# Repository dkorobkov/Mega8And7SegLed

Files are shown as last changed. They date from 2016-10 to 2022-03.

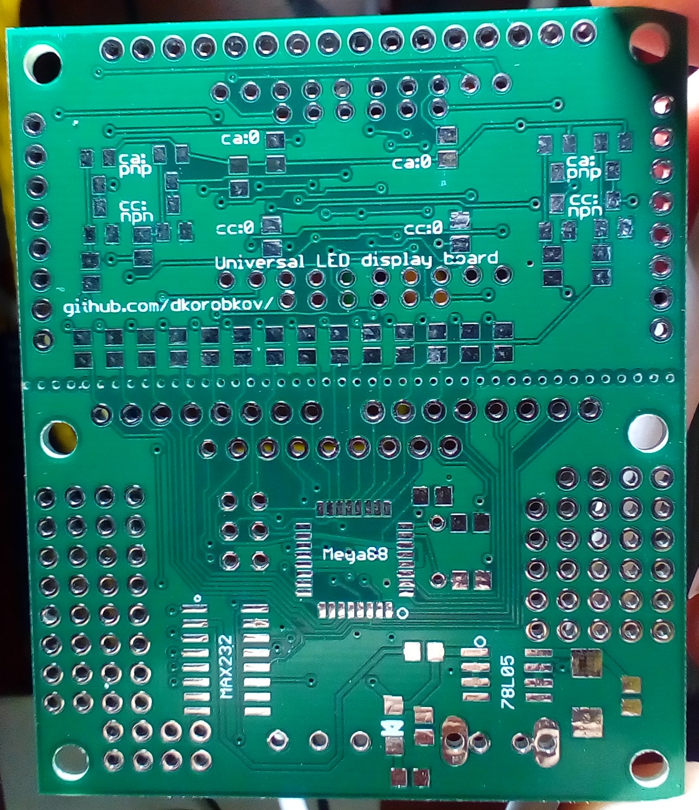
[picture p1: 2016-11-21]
board_bottom.JPG

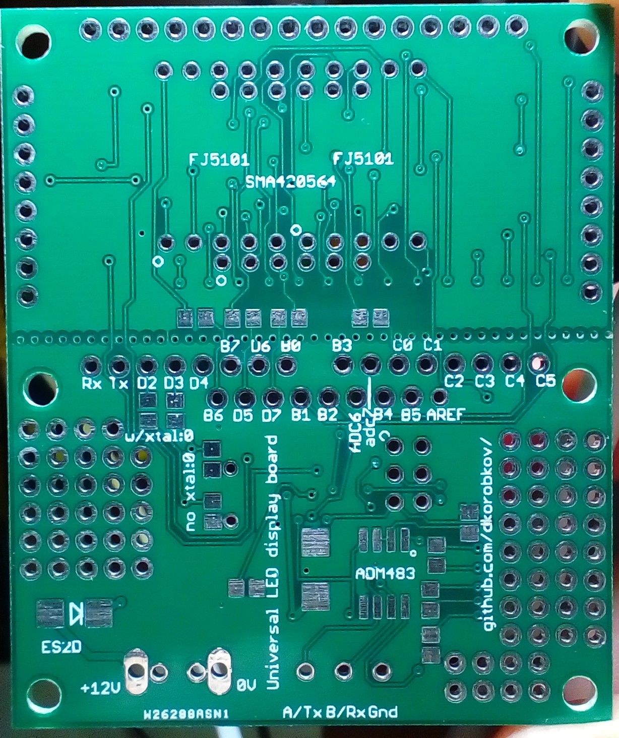
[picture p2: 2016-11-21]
board_top.JPG

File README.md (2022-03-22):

# Mega8And7SegLed
Universal PCB (55*65 mm) with Atmega8 (TQFP32), VUSB and 2-4 digit 7-segment LED (or chinese "Nokia 5110" LCD) for generic projects. EAGLE files and Gerber, Atmel Studio 6.2 example project (C).

See https://github.com/dkorobkov/Mega8And7SegLed/blob/master/board_top.JPG for board look and 
https://github.com/dkorobkov/Mega8And7SegLed/blob/master/LEDBoard.mp4 for its operation.

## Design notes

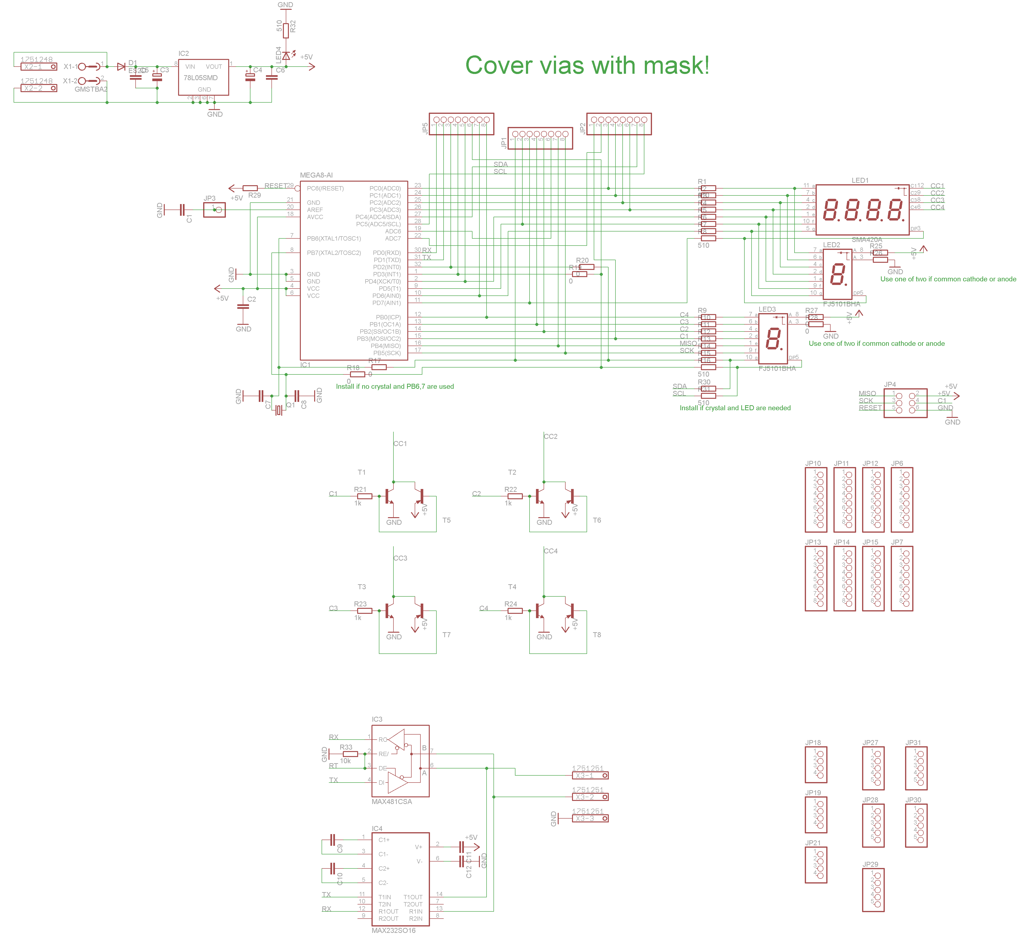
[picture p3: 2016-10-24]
schematic.png

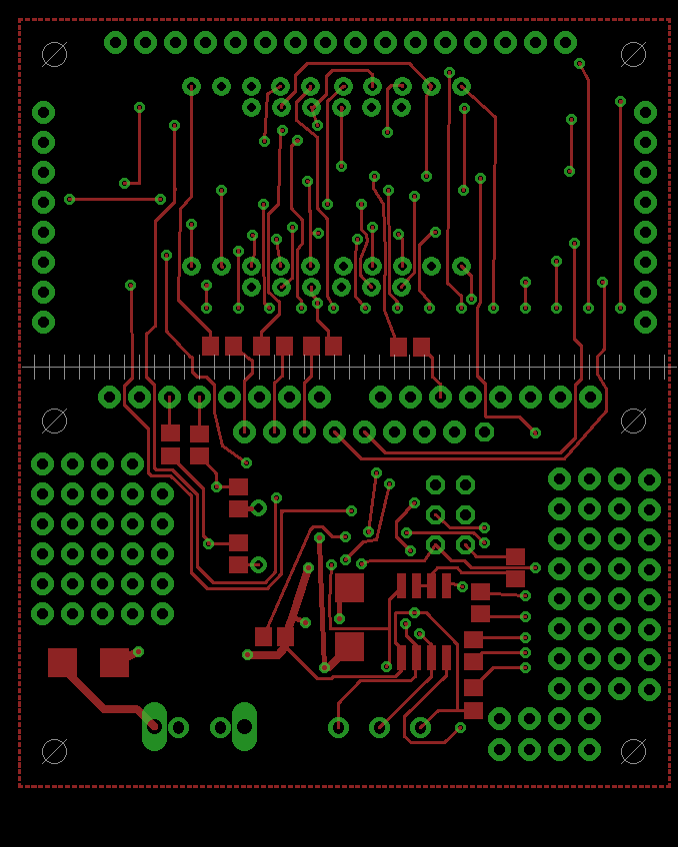
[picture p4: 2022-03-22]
top.png

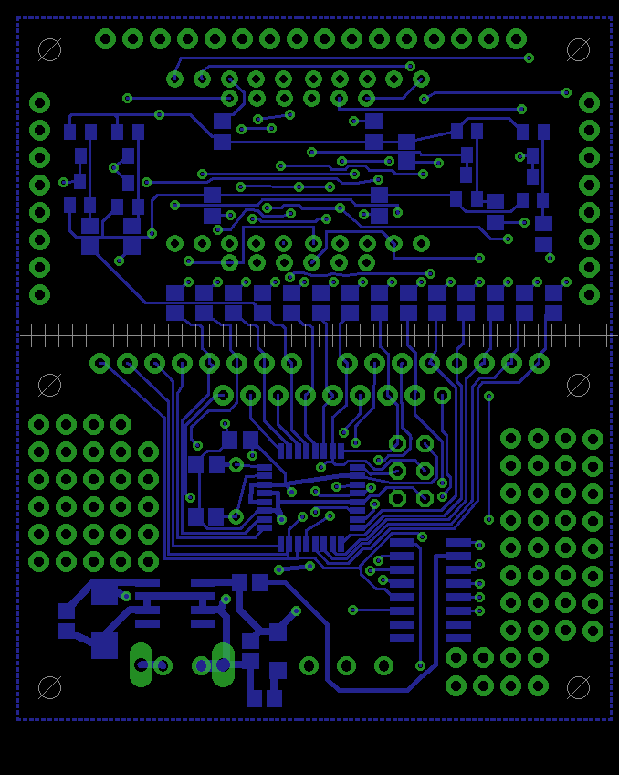
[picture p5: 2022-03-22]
bottom.png

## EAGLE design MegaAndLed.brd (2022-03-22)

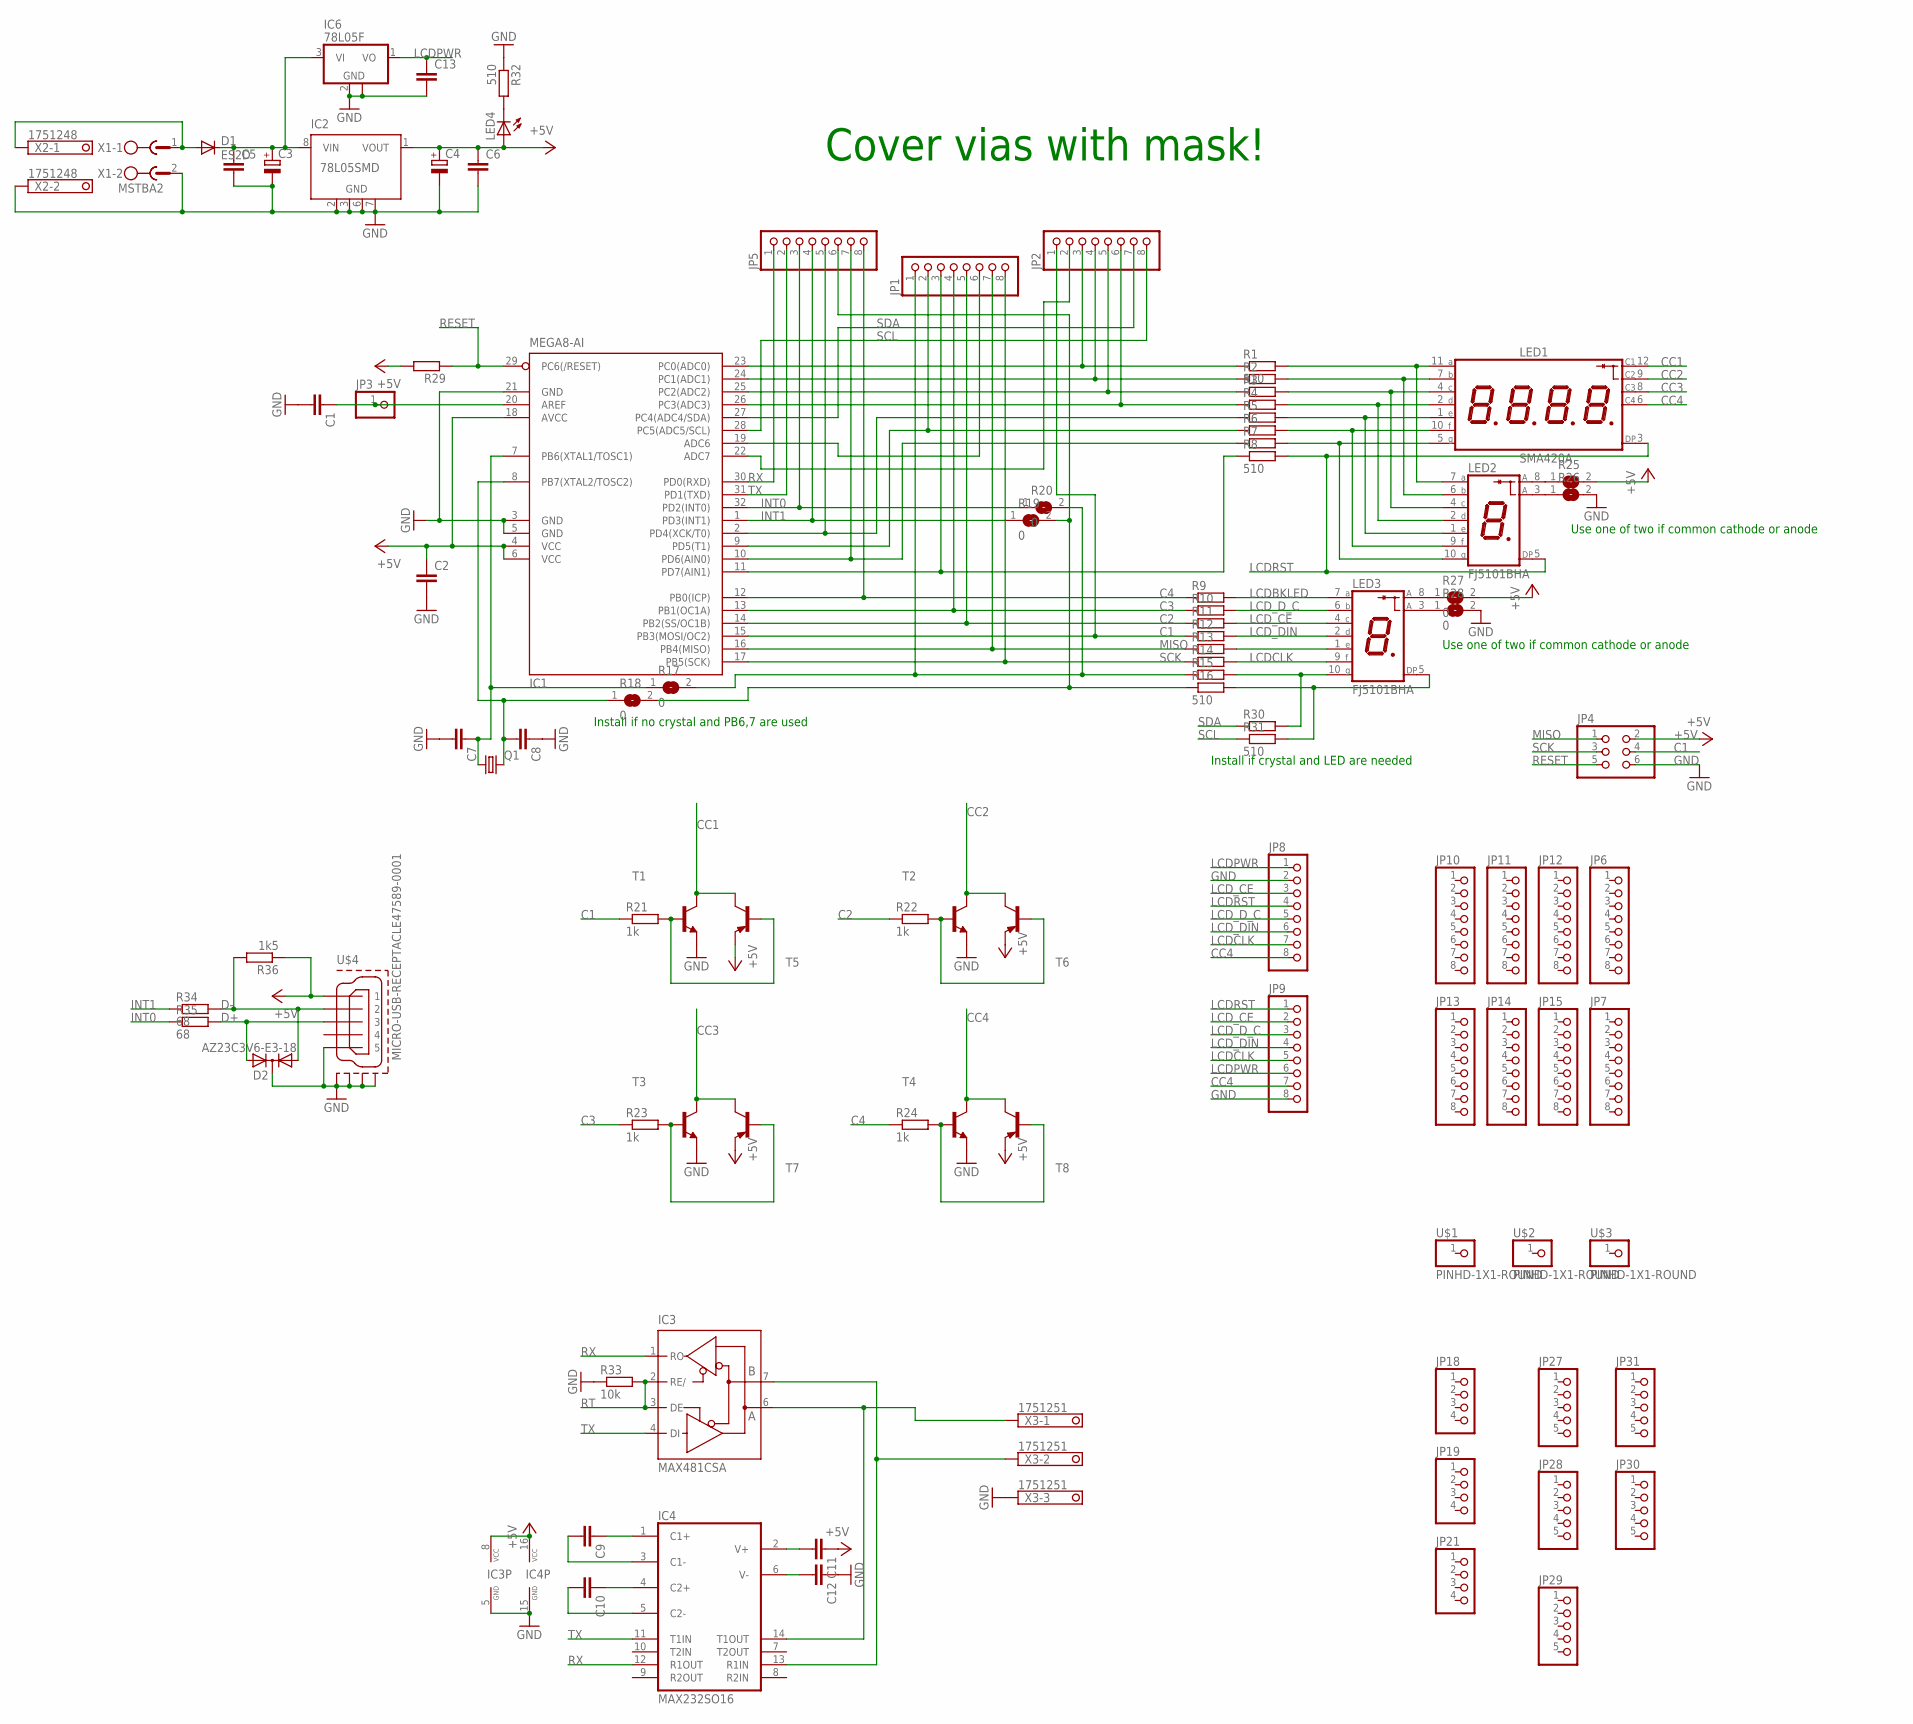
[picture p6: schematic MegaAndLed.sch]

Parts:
C1, C2, C5, C6, C7, C8, C9, C10, C11, C12, C13: C-EUC0805; C0805
C3, C4: CPOL-EUSMCC; SMC_C
D1: ES2D; SMB
D2: AZ23C3V6-E3-18; SOT23
IC1: MEGA8-AI; TQFP32-08
IC2: 78L05SMD; SO08
IC3: MAX481CSA; SO08
IC4: MAX232SO16; SO16
IC6: 78L05F; SOT89
JP1, JP2, JP5, JP6, JP7, JP8, JP9, JP10, JP11, JP12, JP13, JP14, JP15: PINHD-1X8-ROUND; 1X08-ROUND
JP3: PINHD-1X1; 1X01
JP4: PINHD-2X3; 2X03
JP18, JP19, JP21: PINHD-1X4-ROUND; 1X04-ROUND
JP27, JP28, JP29, JP30, JP31: PINHD-1X5-ROUND; 1X05-ROUND
LED1: SMA420A; 7X4-LED
LED2, LED3: FJ5101BHA; LA-401
LED4: LEDCHIPLED_1206; CHIPLED_1206
Q1: CRYSTALHC49U-H; HC49U-H
R1, R8, R16, R31, R32: 510; R0805
R2, R3, R4, R5, R6, R7, R9, R10, R11, R12, R13, R14, R15, R29, R30: R-EU_R0805; R0805
R17, R18, R19, R20, R27, R28: 0; SJ
R21, R22, R23, R24: 1k; R0805
R25, R26: SJ
R33: 10k; R0805
R34, R35: 68; R0805
R36: 1k5; R0805
T1, T2, T3, T4: BCW31-NPN-SOT23-BEC; SOT23-BEC
T5, T6, T7, T8: MMBTA56-SOT23; SOT23
U$1, U$2, U$3: PINHD-1X1-ROUND; 1X01-ROUND
U$4: MICRO-USB-RECEPTACLE47589-0001; 47589-0001
X1: MSTBA2
X2: 1751248
X3: 1751251

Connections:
+5V: C2.1, C4.+, C6.1, C11.1, IC1.4 (VCC), IC1.6 (VCC), IC1.18 (AVCC), IC2.1 (VOUT), IC3.8 (VCC), IC4.16 (VCC), JP4.2, LED4.A, R25.2, R27.2, R29.2, R36.1, T5.2 (E), T6.2 (E), T7.2 (E), T8.2 (E), U$4.1
C1: IC1.15 (PB3(MOSI/OC2)), JP2.1, JP4.4, R12.1, R21.1
C2: IC1.14 (PB2(SS/OC1B)), JP1.5, R11.1, R22.1
C3: IC1.13 (PB1(OC1A)), JP1.4, R10.1, R23.1
C4: IC1.12 (PB0(ICP)), JP5.8, R9.1, R24.1
CC1: LED1.12 (C), T1.C, T5.3 (C)
CC2: LED1.9 (C), T2.C, T6.3 (C)
CC3: LED1.8 (C), T3.C, T7.3 (C)
CC4: JP8.8, JP9.7, LED1.6 (C), T4.C, T8.3 (C)
D+: D2.2 (A2), R35.2, U$4.3
D-: D2.1 (A1), R34.2, R36.2, U$4.2
GND: C1.2, C2.2, C3.-, C4.-, C5.2, C6.2, C7.2, C8.1, C12.1, C13.2, D2.3 (C), IC1.3 (GND), IC1.5 (GND), IC1.21 (GND), IC2.2 (GND), IC2.3 (GND), IC2.6 (GND), IC2.7 (GND), IC3.5 (GND), IC4.15 (GND), IC6.2 (GND), IC6.2@1 (GND), JP4.6, JP8.2, JP9.8, R26.2, R28.2, R32.1, R33.1, T1.E, T2.E, T3.E, T4.E, U$4.5, U$4.CASING1 (GND1), U$4.CASING2 (GND2), U$4.CASING3 (GND3), U$4.CASING4 (GND4), X1.2, X2.2, X3.3
INT0: IC1.32 (PD2(INT0)), JP5.3, R20.1, R35.1
INT1: IC1.1 (PD3(INT1)), JP5.4, R19.1, R34.1
LCDBKLED: LED3.7 (A), R9.2
LCDCLK: JP8.7, JP9.5, LED3.9 (F), R14.2
LCDPWR: C13.1, IC6.1 (VO), JP8.1, JP9.6
LCDRST: JP8.4, JP9.1, LED1.3 (DP), LED2.5 (DP), R8.2
LCD_CE: JP8.3, JP9.2, LED3.4 (C), R11.2
LCD_DIN: JP8.6, JP9.4, LED3.2 (D), R12.2
LCD_D_C: JP8.5, JP9.3, LED3.6 (B), R10.2
MISO: IC1.16 (PB4(MISO)), JP1.7, JP4.1, R13.1
unnamed: C3.+, C5.1, D1.C, IC2.8 (VIN), IC6.3 (VI)
unnamed: IC1.23 (PC0(ADC0)), JP2.3, R1.1
unnamed: IC1.24 (PC1(ADC1)), JP2.4, R2.1
unnamed: IC1.25 (PC2(ADC2)), JP2.5, R3.1
unnamed: R21.2, T1.B, T5.1 (B)
unnamed: R22.2, T2.B, T6.1 (B)
unnamed: IC1.26 (PC3(ADC3)), JP2.6, R4.1
unnamed: C1.1, IC1.20 (AREF), JP3.1
unnamed: LED2.8 (C), R25.1
unnamed: LED2.3 (C), R26.1
unnamed: LED3.8 (C), R27.1
unnamed: LED3.3 (C), R28.1
unnamed: IC1.19 (ADC6), JP1.6
unnamed: IC1.2 (PD4(XCK/T0)), JP5.5, R5.1
unnamed: R23.2, T3.B, T7.1 (B)
unnamed: R24.2, T4.B, T8.1 (B)
unnamed: IC1.22 (ADC7), JP2.2
unnamed: IC1.9 (PD5(T1)), JP1.2, R6.1
unnamed: IC1.10 (PD6(AIN0)), JP5.7, R7.1
unnamed: LED4.C, R32.2
unnamed: C9.1, IC4.1 (C1+)
unnamed: D1.A, X1.1, X2.1
unnamed: C10.1, IC4.4 (C2+)
unnamed: IC1.11 (PD7(AIN1)), JP1.3, R8.1
unnamed: C8.2, IC1.8 (PB7(XTAL2/TOSC2)), Q1.2, R18.1
unnamed: C10.2, IC4.5 (C2-)
unnamed: C9.2, IC4.3 (C1-)
unnamed: C11.2, IC4.2 (V+)
unnamed: JP5.6, R16.1, R18.2, R19.2
unnamed: LED1.11 (A), LED2.7 (A), R1.2
unnamed: LED1.7 (B), LED2.6 (B), R2.2
unnamed: LED1.4 (C), LED2.4 (C), R3.2
unnamed: LED1.2 (D), LED2.2 (D), R4.2
unnamed: LED1.1 (E), LED2.1 (E), R5.2
unnamed: LED1.10 (F), LED2.9 (F), R6.2
unnamed: LED1.5 (G), LED2.10 (G), R7.2
unnamed: LED3.1 (E), R13.2
unnamed: LED3.10 (G), R15.2, R30.2
unnamed: LED3.5 (DP), R16.2, R31.2
unnamed: C12.2, IC4.6 (V-)
unnamed: JP1.1, R15.1, R17.2, R20.2
unnamed: IC3.6 (A), IC4.14 (T1OUT), X3.1
unnamed: IC3.7 (B), IC4.13 (R1IN), X3.2
unnamed: C7.1, IC1.7 (PB6(XTAL1/TOSC1)), Q1.1, R17.1
RESET: IC1.29 (PC6(/RESET)), JP4.5, R29.1
RT: IC3.2 (RE/), IC3.3 (DE), R33.2
RX: IC1.30 (PD0(RXD)), IC3.1 (RO), IC4.12 (R1OUT), JP5.1
SCK: IC1.17 (PB5(SCK)), JP1.8, JP4.3, R14.1
SCL: IC1.28 (PC5(ADC5/SCL)), JP2.8, R31.1
SDA: IC1.27 (PC4(ADC4/SDA)), JP2.7, R30.1
TX: IC1.31 (PD1(TXD)), IC3.4 (DI), IC4.11 (T1IN), JP5.2

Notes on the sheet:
Install if crystal and LED are needed
Use one of two if common cathode or anode
Install if no crystal and PB6,7 are used
Cover vias with mask!

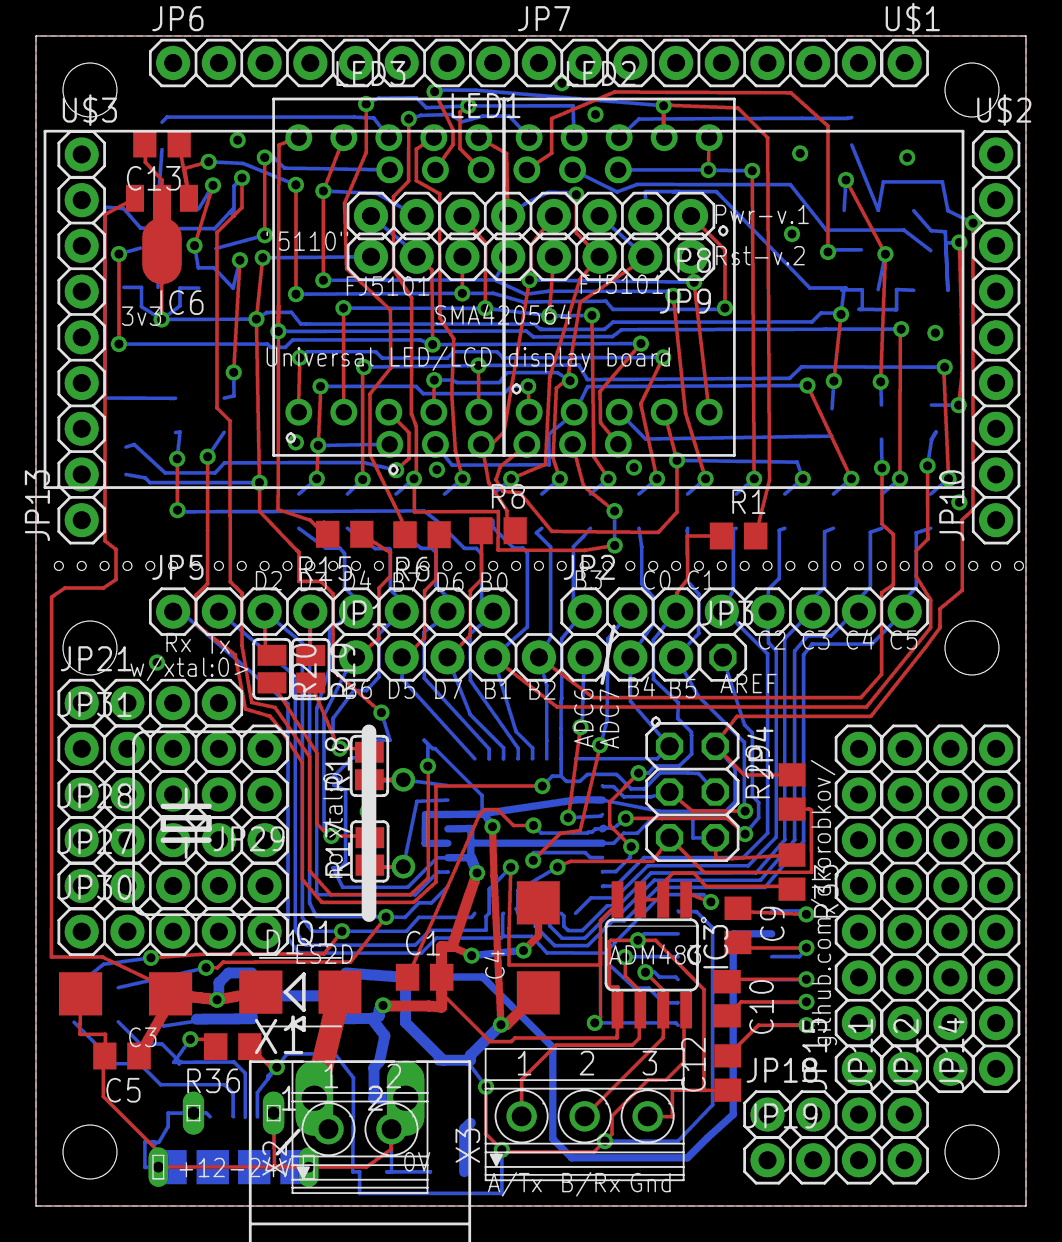
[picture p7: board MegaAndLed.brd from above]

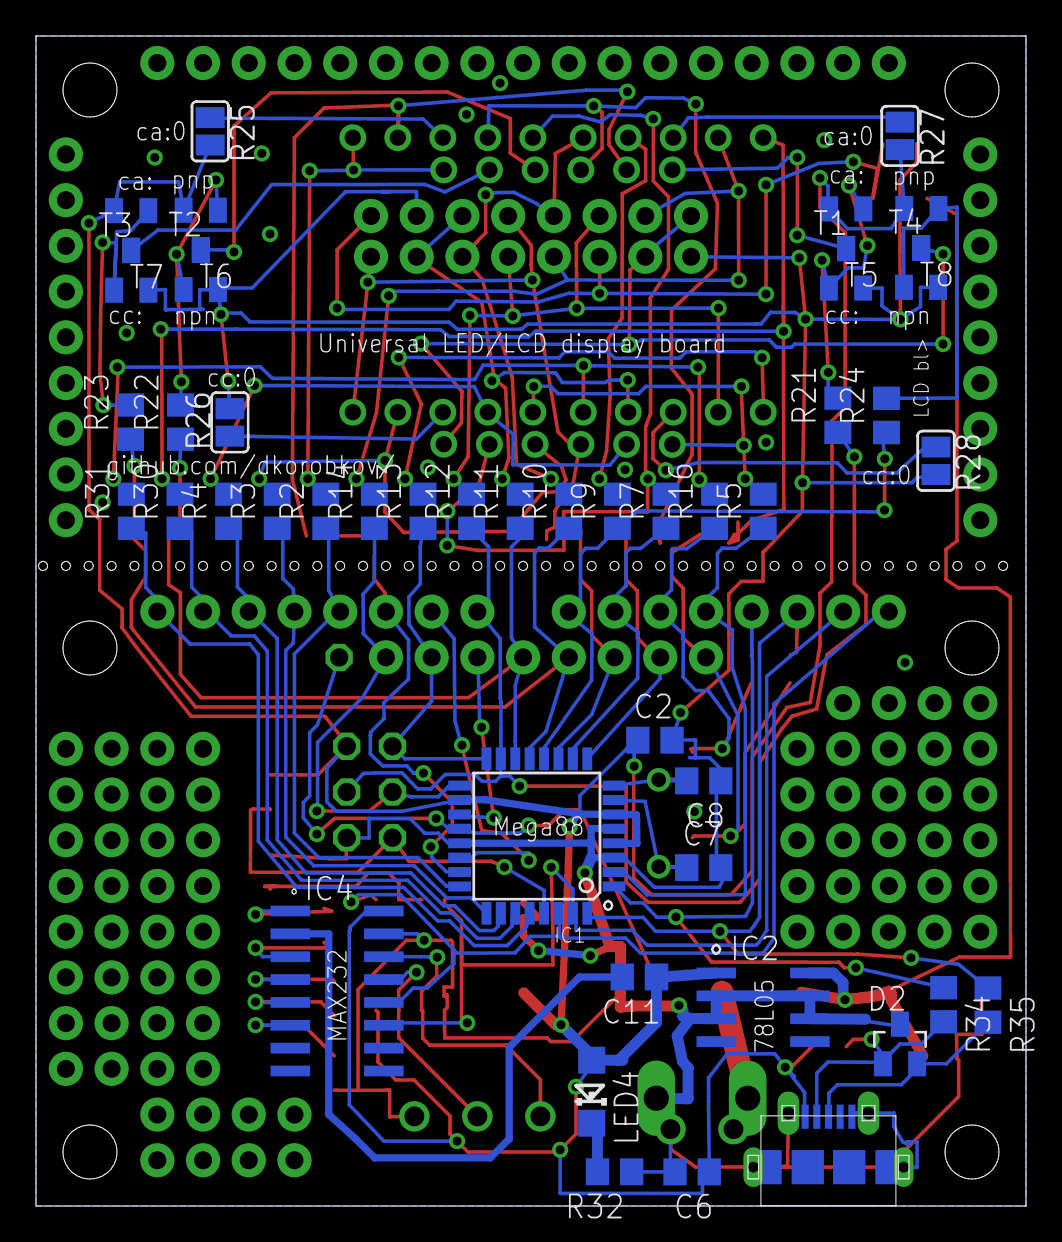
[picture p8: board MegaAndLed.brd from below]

Board: 2 copper layers, 55.0 x 65.0 mm, 99 parts (44 on the bottom side), 73 nets.

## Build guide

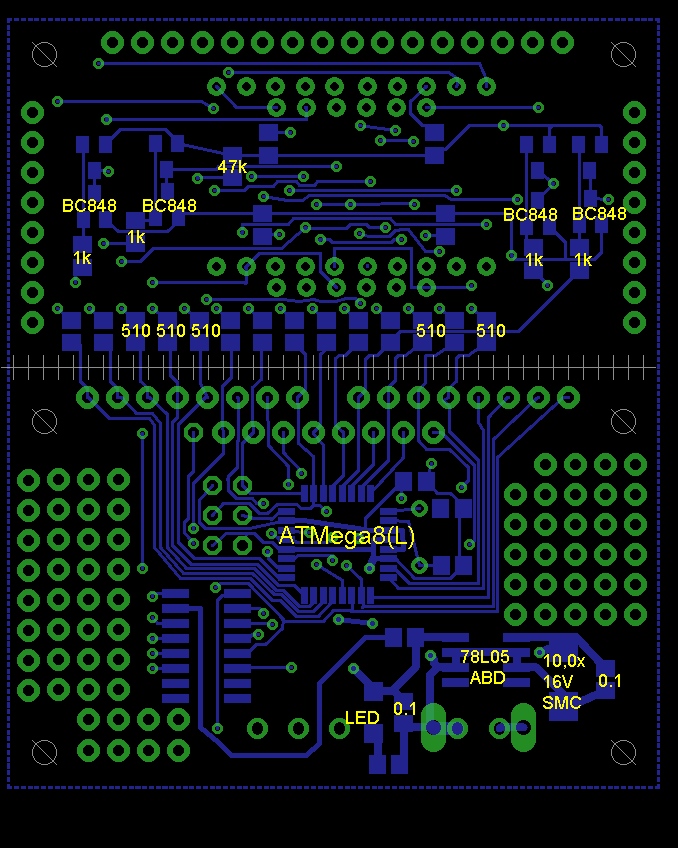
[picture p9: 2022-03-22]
solder_bottom_4led.png

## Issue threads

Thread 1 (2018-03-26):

Missing wire

dkorobkov, 2018-03-26:
Quartz pad coming from PB7 is not connected to jumper that goes to the rest of circuit.

Closed 2020-02-24.

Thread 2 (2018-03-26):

Missing power

dkorobkov, 2018-03-26:
Power+ to ADM485/232 is missing

Closed 2020-02-24.

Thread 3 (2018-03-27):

Power supply connector

dkorobkov, 2018-03-27:
Power supply unit connector is somewhy 7.68 mm. Replace to 5.08.

Closed 2020-02-24.

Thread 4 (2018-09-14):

Reset pullup

dkorobkov, 2018-09-14:
Need to move reset pullup onto main board area so that cutting out indicator does not cut off reset pullup.

Closed 2020-02-24.

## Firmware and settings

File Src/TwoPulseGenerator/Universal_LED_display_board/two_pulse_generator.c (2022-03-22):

/*
 
 Генератор двух импульсов, один запускающий, другой сдвигается относительно 
 первого вперёд-назад и его длина тоже настраивается.
 
 Контроллер - ATMega8L
  
  */ 

#define F_CPU 8000000

#include <avr/pgmspace.h>
#include <avr/eeprom.h>
#include <avr/interrupt.h>
#include <util/delay.h>
#include <stdlib.h>
#include <stdio.h>
#include "Indicator.h"
#include "Uart.h"
#include "Menu.h"

//const char PROGMEM String[] = "HELLO Github";
void Timer1Init()
{
	TCNT1 = 0;
	TCCR1A = (0<<WGM11) | (0 << WGM10); // CTC mode
	TCCR1B = (1 << WGM12) |(0 << CS12) | (1 << CS01) | (0 << CS00); // CLK/8, 1 tick/us
	OCR1A = 100; // will interrupt once in 100 us
	
	TIMSK  = (1<<OCIE1A); // Interrupt on reach OCR0A
}

volatile uint16_t ticks = 0;

volatile uint16_t ticksalways = 0;

ISR(TIMER1_COMPA_vect)
{
	static uint8_t localticks = 0;
	
	ticksalways++;
	if(ticksalways > 1000) // 100 ms
		ticksalways = 0;
	
	Update(1);
	
	if(PIND & (1<<PIND0)) // Секундомер работает только когда ему на вход дают 1
	{
		if(++localticks > 10)
		{
			ticks++;
			if(ticks > 9999)
			ticks = 0;
			localticks = 0;
		}	
	}
}

	// Loads OSCCAL value from last EEPROM byte
void LoadOsccal()
{
	OSCCAL = eeprom_read_byte((uint8_t*)E2END);
}

void DelayUs(uint16_t us)
{
	if(us & 0x8000) // Underflow, delay<0
		return;
		
	us += (us>>1);
	while(us-- > 0)
		{asm volatile ("nop");}
}

int main(void)
{
	LoadOsccal();
	
	DelayUs(10);
	DelayUs(50);
	DelayUs(200);
	
	DDRB |= (1<<DDB4) | (1<<DDB5) | (1<<DDB6) | (1<<DDB7); // выходы "открытый коллектор"
	PORTB &= ~((1<<PB4)|(1<<PB5));

	int i=0;
/*	for(i=0; i<10000; i++)
	{
		_delay_us(50);
		PORTB |= (1<<PB4) | (1<<PB6) ; // похоже, битый порт?
		_delay_us(50); // делаем импульс 5 мкс
		PORTB &= ~( (1<<PB4) | (1<<PB6) );
	}
*/

	UART_Init(51); // 51 = 9600 @ 8 MHz
	
/*	uint8_t c = 0;
	while(1)
	{
		USART_Transmit_sync(c++);
		_delay_ms(10);
	}*/
	
	InitIndicator();

	DDRB |= (1<<DDB4) | (1<<DDB5) | (1<<DDB6) | (1<<DDB7); // выходы "открытый коллектор"
	PORTB &= ~((1<<PB4)|(1<<PB5));
	
//	StringToIndicator_P(PSTR("Triggered StoPWAtch-pulsegen"));
	
	StringToIndicator_P(PSTR("TWwO Pulse generator. Uart 9600 ")); // Ww will show W in two chars

	for(i=0; i<15000; i++)
	{
		_delay_us(500);
		Update(1);
	}

	Timer1Init();
	
	sei();		
	
	UART_Putstring_P(PSTR("Two pulse generator. Uart 9600\r\nBuild: " __TIMESTAMP__ "\r\n"));

	
	uint16_t t = ticks;
	
	uint8_t WhatToChange = 0;
	uint8_t PulseLength = 10;
	int16_t Offset = 50;
	
	char s[8];
	itoa(PulseLength, s, 10);
	StringToIndicator(s); // Ww will show W in two chars

	uint8_t bPermanent = 0;
	
    while(1)
    {
		
		//if(ticksalways < 10 ) // any ticks in first 10 ms
		if(ticks - t > 500)
		{			
			cli(); // ЧТобы никто не вмешался в точную генерацию импульса
			
			//ticksalways = 10; // чтобы мы в следующий раз ввалились сбда только через 1 с
			t = ticks;
/*                               +----------------------+                                                                       
                                 |                      |                                                                       
                                 |                      |                                                                       
                                 |                      |                                                                       
              +---+  offset > 5  |                      |                                                                            
Light         |   |              |                      |                                                                         
---------------------------------+                      +--------------------------------------                                   
              |   |                                                                                                               
              |   |                                                                                                               
              |   |                                                                                                               
Trig          |   |                                                                                                               
--------------+   +---------------------------------------------------------------------------- */
#define TRIG_WIDTH 5
			if(Offset > TRIG_WIDTH)	
			{
				// trigger
				PORTB |= (1<<PB5) | (1<<PB7) ; // похоже, битый порт?
				_delay_us(TRIG_WIDTH); // делаем импульс 5 мкс
				PORTB &= ~( (1<<PB5) | (1<<PB7) );

				DelayUs(Offset-TRIG_WIDTH); 
			
				// light
				PORTB |= (1<<PB4) | (1<<PB6) ; // похоже, битый порт?
				DelayUs(PulseLength); // делаем импульс 5 мкс 
				if(bPermanent == 0)
					PORTB &= ~( (1<<PB4) | (1<<PB6) );
			}
/*                               +----------------------+                                                                       
                                 |                      |                                                                       
                                 |                      |                                                                       
                                 |                      |                                                                       
              0 < offset < 5   +---+                    |                                                                                                  
Light                          | | |                    |                                                                                              
---------------------------------+ |                    +--------------------------------------                                   
                               |   |                                                                                                               
                               |   |                                                                                                               
                               |   |                                                                                                               
Trig                           |   |                                                                                                               
-------------------------------+   +---------------------------------------------------------------------------- */
			else if(Offset > 0)	
			{
				// trigger
				PORTB |= (1<<PB5) | (1<<PB7) ; // похоже, битый порт?
				DelayUs(Offset); // делаем импульс 5 мкс

				// light
				PORTB |= (1<<PB4) | (1<<PB6) ; // похоже, битый порт?

				DelayUs(TRIG_WIDTH - Offset); // делаем остаток импульса
				PORTB &= ~( (1<<PB5) | (1<<PB7) ); // trigger off

				DelayUs(PulseLength - TRIG_WIDTH + Offset); // остаток импульса света
				
				if(bPermanent == 0)
					PORTB &= ~( (1<<PB4) | (1<<PB6) );
			}
/*                           +----------------------+                                                                       
                             |                      |                                                                       
                             |                      |                                                                       
                             |                      |                                                                       
                  offset < 0 |  o  +---+            |                                                                                                  
Light                        |     |   |            |                                                                                              
-----------------------------+     |   |            +--------------------------------------                                   
                                   |   |                                                                                                               
                                   |   |                                                                                                               
                                   |   |                                                                                                               
Trig                               |   |                                                                                                               
-----------------------------------+   +---------------------------------------------------------------------------- */
			else if(Offset > 0)	
			{
				// light
				PORTB |= (1<<PB4) | (1<<PB6) ; // похоже, битый порт?

				DelayUs(0 - Offset); // делаем остаток импульса

				// trigger
				PORTB |= (1<<PB5) | (1<<PB7) ; // похоже, битый порт?
				DelayUs(TRIG_WIDTH); // делаем импульс 5 мкс

				PORTB &= ~( (1<<PB5) | (1<<PB7) ); // trigger off

				DelayUs(PulseLength - TRIG_WIDTH + Offset); // остаток импульса света
				
				if(bPermanent == 0)
					PORTB &= ~( (1<<PB4) | (1<<PB6) );
			}
			
			sei();
		}
		
/*		if(t != ticks)
		{
			t = ticks;
			
			char str[10];
			sprintf(str, "%04d", ticks);
			StringToIndicator(str);			
		}*/
		
		
		if(WhatToChange == 'L')
		{
			s[0]='L'; s[1] = ' ';
			itoa(PulseLength, s+1, 10);
			StringToIndicator(s); // Ww will show W in two chars
		}
		else if(WhatToChange == 'O')
		{
			s[0]='o'; s[1] = ' ';
			itoa(Offset, s+1, 10);
			StringToIndicator(s); 
		}
		else StringToIndicator_P(PSTR("L-O")); 
		
		if(UART_rxready() > 0)
		{
			char c = UART_recv_char();
			switch(c)
			{
				case 'P': bPermanent = 1; break;
				case 'p': bPermanent = 0; break;
				case 'L': case 'l': 
					WhatToChange = 'L'; 
					UART_Putstring_P(PSTR("Length = "));
					UART_Putstring_itoa(PulseLength);
					UART_Putstring_P(PSTR("\r\n"));
					break;
				case 'O': case 'o':
					WhatToChange = 'O';
					UART_Putstring_P(PSTR("Offset = "));
					UART_Putstring_itoa(Offset);
					UART_Putstring_P(PSTR("\r\n"));
					break;
				case '+': 
					if(WhatToChange == 'L')
					{
						PulseLength++;
						UART_Putstring_P(PSTR("Length = "));
						UART_Putstring_itoa(PulseLength);
						UART_Putstring_P(PSTR("\r\n"));
					}
					if(WhatToChange == 'O')
					{
						Offset++;
						UART_Putstring_P(PSTR("Offset = "));
						UART_Putstring_itoa(Offset);
						UART_Putstring_P(PSTR("\r\n"));
					}
					break;
				case '-':
					if(WhatToChange == 'L' && PulseLength > 5)
					{
						PulseLength--;
						UART_Putstring_P(PSTR("Length = "));
						UART_Putstring_itoa(PulseLength);
						UART_Putstring_P(PSTR("\r\n"));
					}
					if(WhatToChange == 'O')
					{
						Offset--;
						UART_Putstring_P(PSTR("Offset = "));
						UART_Putstring_itoa(Offset);
						UART_Putstring_P(PSTR("\r\n"));
					}
					break;
				default: UART_Putstring_P(PSTR("L - set pulse length, O - set offset from trigger to LED pulse, +- - change selected value, Pp - LED permanent on/off\r\n")); break;
			}
			
		}
		
//		Menu();
    }
}

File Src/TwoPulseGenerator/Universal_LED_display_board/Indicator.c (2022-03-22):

/*
 * Indicator.c
 *
 * Created: 12.12.2016 17:53:01
 *  Author: https://github.com/dkorobkov
 */ 

#include <avr/pgmspace.h>
#include <avr/io.h>
#include <string.h>

#include "Indicator.h"

// Check for errors
#ifndef NUM_DIGITS 
	#error You must define NUM_DIGITS
#endif
	
#if NUM_DIGITS != 2 && NUM_DIGITS != 4
	#error NUM_DIGITS must be 2 or 4
#endif

#ifndef COMMON_PIN
#error You must define COMMON_PIN
#endif

#if COMMON_PIN != COMMON_CATHODE && COMMON_PIN != COMMON_ANODE
#error COMMON_PIN must be COMMON_CATHODE or COMMON_ANODE
#endif


#if COMMON_PIN == COMMON_CATHODE
	#define DIGIT_1_ON  (PORTB |=  (1<<PB3))
	#define DIGIT_1_OFF (PORTB &= ~(1<<PB3))
	#define DIGIT_2_ON  (PORTB |=  (1<<PB2))
	#define DIGIT_2_OFF (PORTB &= ~(1<<PB2))
	#define DIGIT_3_ON  (PORTB |=  (1<<PB1))
	#define DIGIT_3_OFF (PORTB &= ~(1<<PB1))
	#define DIGIT_4_ON  (PORTB |=  (1<<PB0))
	#define DIGIT_4_OFF (PORTB &= ~(1<<PB0))
	#define DIGITS_OFF  (PORTB &= ~( (1<<PB0) | (1<<PB1) | (1<<PB2) | (1<<PB3)))
#endif

#if COMMON_PIN == COMMON_ANODE
#define DIGIT_1_OFF  (PORTB |=  (1<<PB3))
#define DIGIT_1_ON (PORTB &= ~(1<<PB3))
#define DIGIT_2_OFF  (PORTB |=  (1<<PB2))
#define DIGIT_2_ON (PORTB &= ~(1<<PB2))
#define DIGIT_3_OFF  (PORTB |=  (1<<PB1))
#define DIGIT_3_ON (PORTB &= ~(1<<PB1))
#define DIGIT_4_OFF  (PORTB |=  (1<<PB0))
#define DIGIT_4_ON (PORTB &= ~(1<<PB0))
#define DIGITS_OFF  (PORTB |= ( (1<<PB0) | (1<<PB1) | (1<<PB2) | (1<<PB3)))
#endif


/*
	__________________________________________________
	     |   segment values              |            |
	Char |dp | G | F | E | D | C | B | A | hex code   |
	-----|---|---|---|---|---|---|---|---|------------|
	  0  | 0 | 0 | 1 | 1 | 1 | 1 | 1 | 1 |    3f      |
	  1  | 0 | 0 | 0 | 0 | 0 | 1 | 1 | 0 |    06      |
	  2  | 0 | 1 | 0 | 1 | 1 | 0 | 1 | 1 |    5b      |
	  3  | 0 | 1 | 0 | 0 | 1 | 1 | 1 | 1 |    4f      |
	  4  | 0 | 1 | 1 | 0 | 0 | 1 | 1 | 0 |    66      |
	  5  | 0 | 1 | 1 | 0 | 1 | 1 | 0 | 1 |    6d      |
	  6  | 0 | 1 | 1 | 1 | 1 | 1 | 0 | 1 |    7d      |
	  7  | 0 | 0 | 0 | 0 | 0 | 1 | 1 | 1 |    07      |
	  8  | 0 | 1 | 1 | 1 | 1 | 1 | 1 | 1 |    7f      |
	  9  | 0 | 1 | 1 | 0 | 1 | 1 | 1 | 1 |    6f      |
	  A  | 0 | 1 | 1 | 1 | 0 | 1 | 1 | 1 |    77      |
	  b  | 0 | 1 | 1 | 1 | 1 | 1 | 0 | 0 |    7c      |
	  C  | 0 | 0 | 1 | 1 | 1 | 0 | 0 | 1 |    39      |
	  d  | 0 | 1 | 0 | 1 | 1 | 1 | 1 | 0 |    5e      |
	  E  | 0 | 1 | 1 | 1 | 1 | 0 | 0 | 1 |    79      |
	  F  | 0 | 1 | 1 | 1 | 0 | 0 | 0 | 1 |    71      |
	 .   | 1 | 0 | 0 | 0 | 0 | 0 | 0 | 0 |    80      |
	-----|---|---|---|---|---|---|---|---|------------|
	  a  | 0 | 1 | 0 | 1 | 1 | 1 | 1 | 1 |    5f      |
	  c  | 0 | 1 | 0 | 1 | 1 | 0 | 0 | 0 |    58      |
	  e  | 0 | 1 | 1 | 1 | 1 | 0 | 1 | 1 |    7b      |
	  G  | 0 | 1 | 1 | 1 | 1 | 1 | 0 | 1 |    7d      |
	  H  | 0 | 1 | 1 | 1 | 0 | 1 | 1 | 0 |    75      |
	  h  | 0 | 1 | 1 | 1 | 0 | 1 | 0 | 0 |    74      |
	  I  | 0 | 0 | 0 | 0 | 0 | 1 | 1 | 0 |    06      |
	  i  | 0 | 0 | 0 | 0 | 0 | 1 | 0 | 0 |    04      |
	  J  | 0 | 0 | 0 | 1 | 1 | 1 | 1 | 0 |    1e      |
	  L  | 0 | 0 | 1 | 1 | 1 | 0 | 0 | 0 |    38      |
	  l  | 0 | 0 | 1 | 1 | 0 | 0 | 0 | 0 |    30      |
	  n  | 0 | 1 | 0 | 1 | 0 | 1 | 0 | 0 |    54      |
	  o  | 0 | 1 | 0 | 1 | 1 | 1 | 0 | 0 |    5c      |
	  P  | 0 | 1 | 1 | 1 | 0 | 0 | 1 | 1 |    73      |
	  q  | 0 | 1 | 1 | 0 | 0 | 1 | 1 | 1 |    67      |
	  r  | 0 | 1 | 0 | 1 | 0 | 0 | 0 | 0 |    50      |
	  t  | 0 | 1 | 1 | 1 | 1 | 0 | 0 | 0 |    78      |
	  U  | 0 | 0 | 1 | 1 | 1 | 1 | 1 | 0 |    3e      |
	  u  | 0 | 0 | 0 | 1 | 1 | 1 | 0 | 0 |    1c      |
	  Y  | 0 | 1 | 1 | 0 | 1 | 1 | 1 | 0 |    6e      |
	  °  | 0 | 1 | 1 | 0 | 0 | 0 | 1 | 1 |    63      |
	  -  | 0 | 1 | 0 | 0 | 0 | 0 | 0 | 0 |    40      |
	  =  | 0 | 1 | 0 | 0 | 1 | 0 | 0 | 0 |    48      |
	  _  | 0 | 0 | 0 | 0 | 1 | 0 | 0 | 0 |    08      |
	 .   | 1 | 0 | 0 | 0 | 0 | 0 | 0 | 0 |    80      |
	  !  | 1 | 0 | 0 | 0 | 0 | 1 | 1 | 0 |    86      |
	  "  | 0 | 0 | 1 | 0 | 0 | 0 | 0 | 1 |    21      |
	  %  | 0 | 0 | 1 | 0 | 0 | 0 | 1 | 0 |            |
	-----*---*---*---*---*---*---*---*---*------------*
*/

// Starting from ' ', ASCII below 0x20 are non printable
unsigned char PROGMEM const ToHexDigit[128-32] = 
{
0x00, 0x86, 0x22, 0x08, 0x08, 0x08, 0x08, 0x02, //  !"#$%&'
0x39, 0x0f, 0x08, 0x46, 0x80, 0x40, 0x80, 0x08, // ()*+,-./
0x3f, 0x06, 0x5b, 0x4f, 0x66, 0x6d, 0x7d, 0x07,	//	01234567
0x7f, 0x6f, 0x08, 0x08, 0x08, 0x48, 0x08, 0x53,	//  89:;<=>?
0x08, 0x77, 0x7c, 0x39, 0x5e, 0x79, 0x71, 0x3d,	//  @ABCDEFG
0x76, 0x06, 0x0E, 0x08, 0x38, 0x54, 0x54, 0x3f,	//  HIJKLMNO
0x73, 0x67, 0x31, 0x6d, 0x78, 0x3e, 0x08, /*0x08*/0x3c,	//  PQRSTUVW
0x08, 0x6e, 0x49, 0x39, 0x08, 0x0f, 0x01, 0x08,	//  XYZ[\]^_
0x20, 0x5f, 0x7c, 0x58, 0x5e, 0x7b, 0x71, 0x3d,	//  `abcdefg
0x74, 0x04, 0x0c, 0x08, 0x30, 0x08, 0x54, 0x5c,	//  hijklmno   
0x73, 0x67, 0x50, 0x6d, 0x78, 0x1c, 0x08, /*0x08*/0x1e,	//  pqrstuvw
0x08, 0x6e, 0x49, 0x39, 0x30, 0x0f, 0x40, 0x5d	//  xyz{|}~?
};

#define DECIMAL_POINT 0x80
 
// if next char is '.' we'll fit it into the same segment.
static unsigned char CharTo7Seg(unsigned char c, unsigned char NextValue)
{
	unsigned char mask = 0x0;
	
	// add decimal point
	if( NextValue == '.' || NextValue == ',')
		mask = 0x80; // Turn on '.'
	
	if(c == '°') // Useful special character
		return mask | 0x63;	
	
	if(c == 0)
		return mask;
	
	if(c < ' ' || c > 127)
		mask |= 0x08; // Underscore for non-printables
	else 
		mask |= pgm_read_byte(&(ToHexDigit[c-' '])); 
		
	return mask;
}

static void Segments(char Value, char NextValue)
{
	// Convert Value to segments on/off	
	unsigned char c = CharTo7Seg(Value, NextValue);
#if COMMON_PIN == COMMON_ANODE
	c = ~c; // Invert output
#endif

#if NUM_DIGITS == 4
	if(c & 0x01) PORTC |= (1<<PC0); else PORTC &= ~(1<<PC0);
	if(c & 0x02) PORTC |= (1<<PC1); else PORTC &= ~(1<<PC1);
	if(c & 0x04) PORTC |= (1<<PC2); else PORTC &= ~(1<<PC2);
	if(c & 0x08) PORTC |= (1<<PC3); else PORTC &= ~(1<<PC3);
	if(c & 0x10) PORTD |= (1<<PD4); else PORTD &= ~(1<<PD4);
	if(c & 0x20) PORTD |= (1<<PD5); else PORTD &= ~(1<<PD5);
	if(c & 0x40) PORTD |= (1<<PD6); else PORTD &= ~(1<<PD6);
	if(c & 0x80) PORTD |= (1<<PD7); else PORTD &= ~(1<<PD7);
#endif
#if NUM_DIGITS == 2
	if(c & 0x01) PORTC |= (1<<PC0); else PORTC &= ~(1<<PC0);
	if(c & 0x02) PORTC |= (1<<PC1); else PORTC &= ~(1<<PC1);
	if(c & 0x04) PORTC |= (1<<PC2); else PORTC &= ~(1<<PC2);
	if(c & 0x08) PORTC |= (1<<PC3); else PORTC &= ~(1<<PC3);
	if(c & 0x10) PORTD |= (1<<PD4); else PORTD &= ~(1<<PD4);
	if(c & 0x20) PORTD |= (1<<PD5); else PORTD &= ~(1<<PD5);
	if(c & 0x40) PORTD |= (1<<PD6); else PORTD &= ~(1<<PD6);
	if(c & 0x80) PORTD |= (1<<PD7); else PORTD &= ~(1<<PD7);
#endif

}
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

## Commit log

2016-11-21 Board received from pcbway.com !
2016-12-12 Source code for ATMega8 to work (yet) with 4-digit LED indicator.
2017-01-17 Example of stopwatch with millisecond precision (used for machine vision camera benchmarking)
2017-01-17 Soldering components for 4-pos 7-seg LED
2017-01-28 Fixed unrouted wire from crystal to R18, C8
    [MegaAndLed.brd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]
2017-01-29 Components to be soldered if using FJ5101BH
2019-01-29 Added settings for common anode LEDs
2019-08-26 Update to work with common anode LED indicators (settable in Indicator.h)
2020-02-26 Fixed many issues found so far. Added chinese "Nokia 5110" LCD connection (two pinouts met in the market) Added microUSB for powering up and V-USB (https://www.obdev.at/products/vusb/index.html)
    [MegaAndLed.brd, MegaAndLed.sch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]
2022-03-22 Two pulse generator with UART for ATMega8L

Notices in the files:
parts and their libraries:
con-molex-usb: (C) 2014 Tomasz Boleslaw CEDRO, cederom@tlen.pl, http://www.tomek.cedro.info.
